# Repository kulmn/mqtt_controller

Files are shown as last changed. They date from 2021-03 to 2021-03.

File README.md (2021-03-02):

# External device controller with timers and MQTT protocol.

Hardware: 
- Schematic diagram (Autodesk EAGLE) in /schematic/ dir
- MCU: STM32L152CB, STM32F030F4 ([firmware](https://github.com/kulmn/lcd_hd44780_f030x4))
- Ethernet: WIZnet W5500
- Indicator: HD44780 16x2

Firmware:
- GCC Eclipse project, FreeRTOS, LibOpenCM3

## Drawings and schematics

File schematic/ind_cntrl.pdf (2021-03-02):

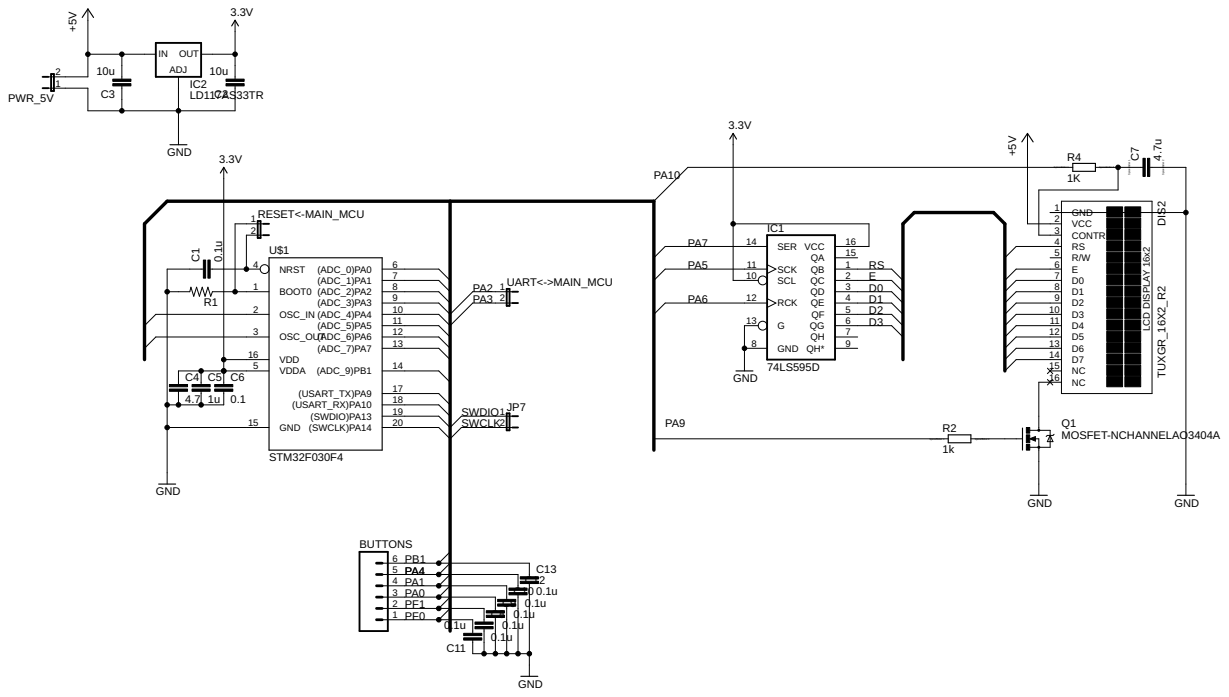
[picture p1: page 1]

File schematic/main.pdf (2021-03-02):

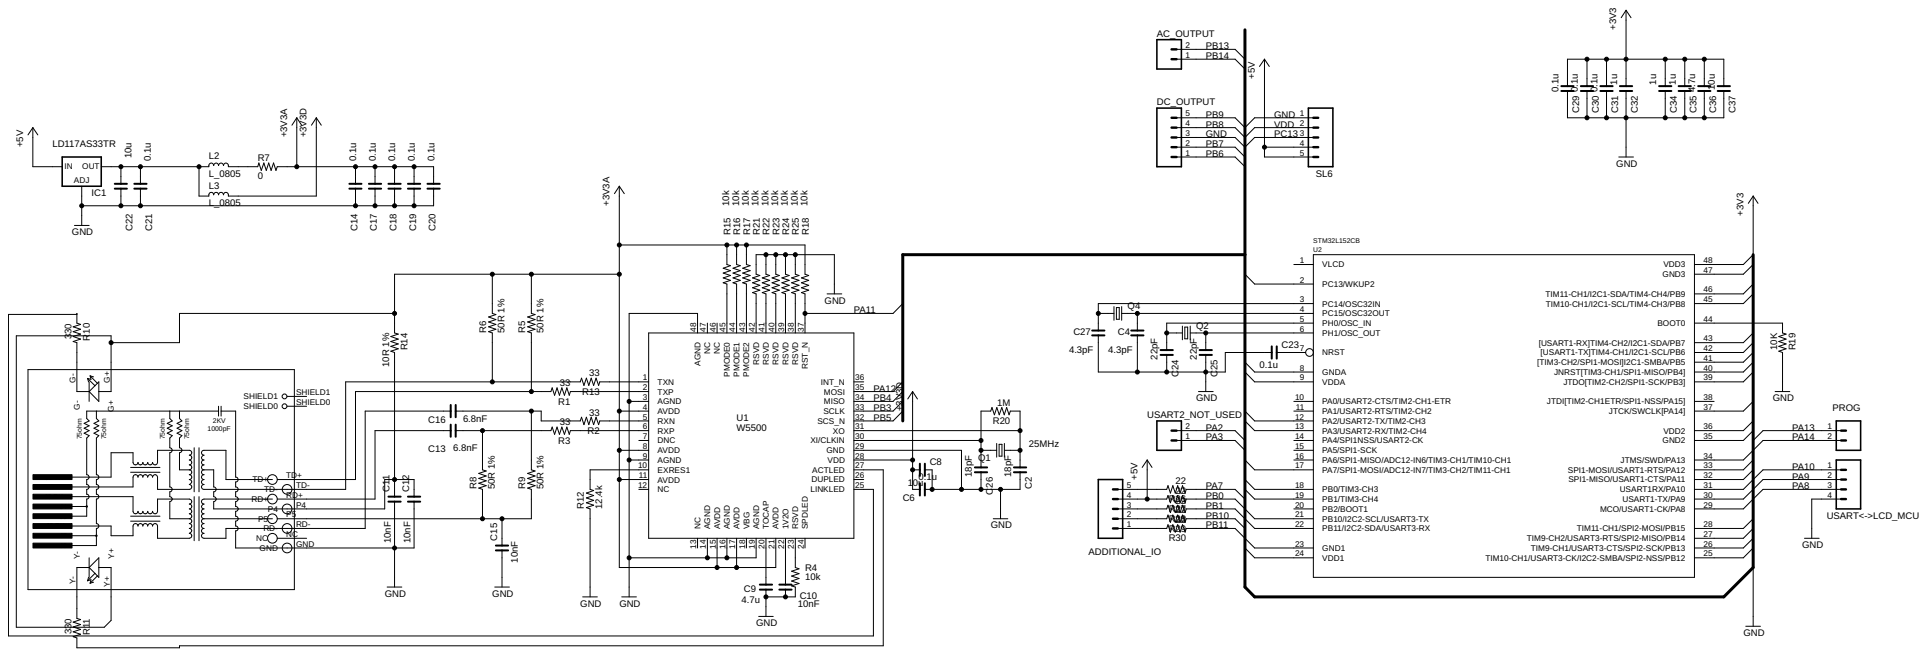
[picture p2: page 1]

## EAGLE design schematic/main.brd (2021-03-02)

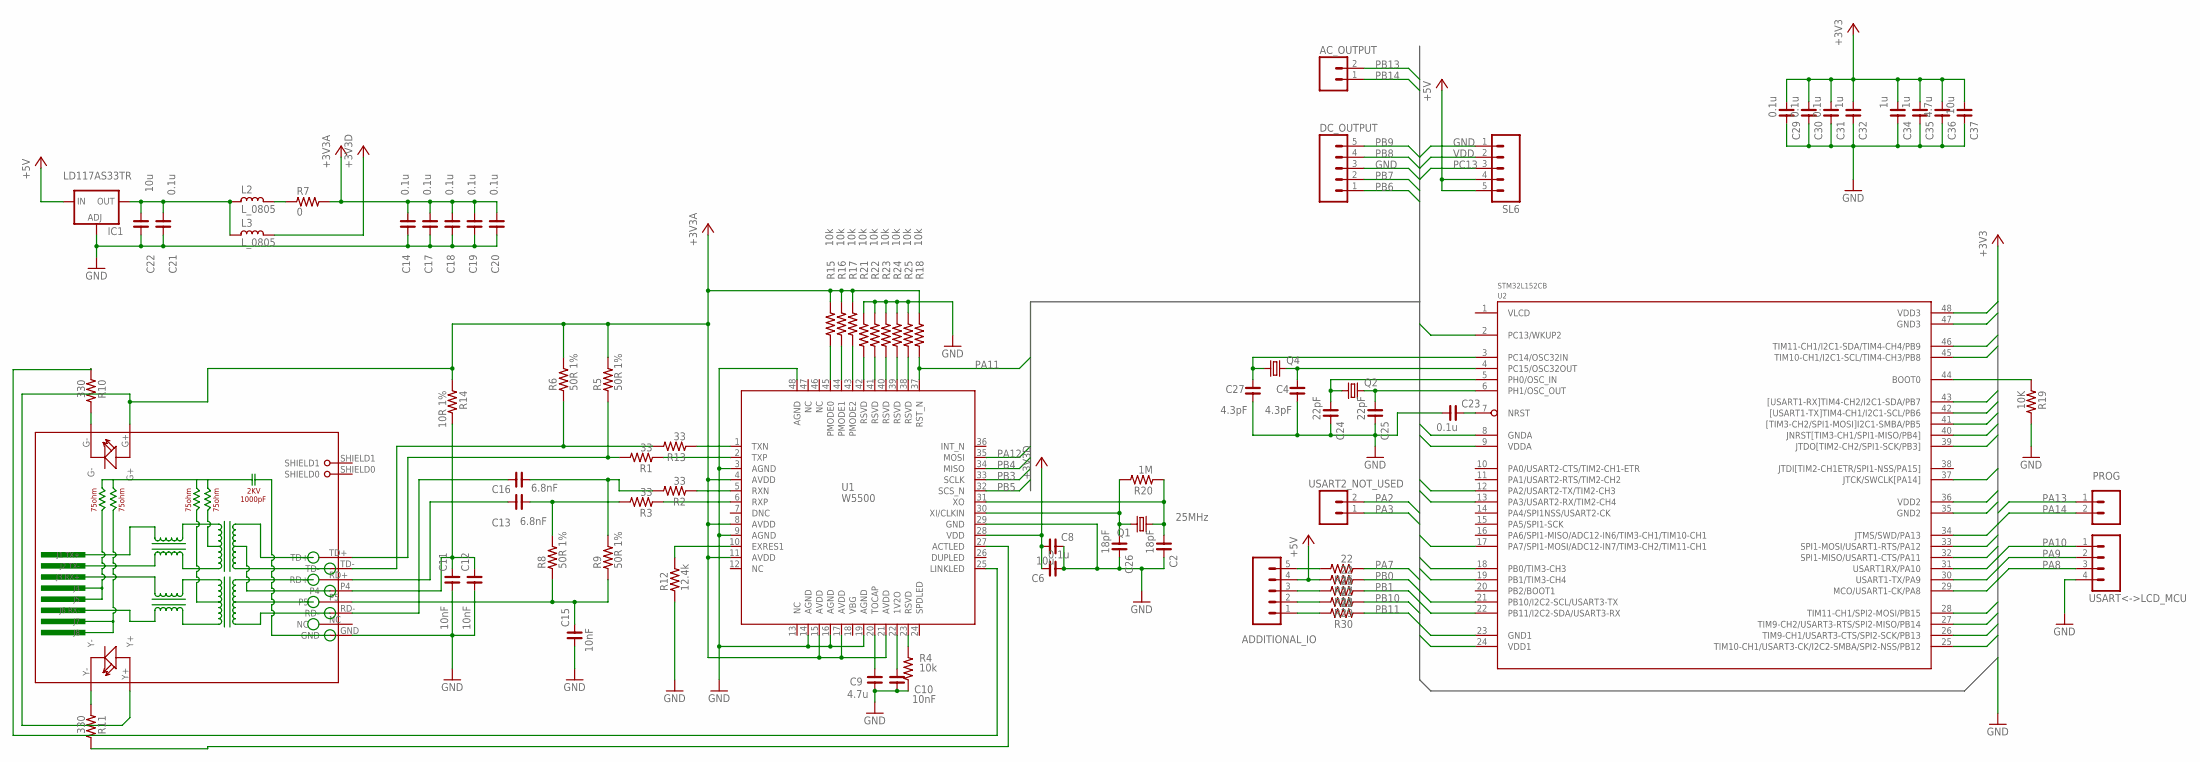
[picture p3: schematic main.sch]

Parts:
AC_OUTPUT: M02; 02P
ADDITIONAL_IO: M05; 05P
C2, C26: 18pF; C0603
C4, C27: 4.3pF; C0603
C6, C14, C17, C18, C19, C20, C21, C23, C29, C30, C31: 0.1u; C0805
C8, C22, C37: 10u; C0805
C9, C36: 4.7u; C0805
C10, C11, C12, C15: 10nF; C0603
C13, C16: 6.8nF; C0603
C24, C25: 22pF; C0805
C32, C34, C35: 1u; C0805
DC_OUTPUT: M05; 05P
IC1: LD117AS33TR; SOT223
L2, L3: L_0805; L0805
PROG: M02; 02P
Q1: 25MHz; HC49U-V
Q2: CRYSTALHC49U-V; HC49U-V
Q4: CRYSTALTC26H; TC26H
R1, R2, R3, R13: 33; R0603
R4, R15, R16, R17, R18, R21, R22, R23, R24, R25: 10k; R0603
R5, R6, R8, R9: 50R 1%; R0603
R7: 0; R1206
R10, R11: 330; R0805
R12: 12.4k; R0805
R14: 10R 1%; R0603
R19: 10K; R1206
R20: 1M; R0805
R26, R27, R28, R29, R30: 22; R0805
RJ1: HR911105A
SL6: M05; 05P
U1: W5500
U2: STM32L152CB; LQFP48-7X7
USART2_NOT_USED: M02; 02P
USART<->LCD_MCU: M04; 04P

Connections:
+3V3A: C14.1, C17.1, C18.1, C19.1, C20.1, R5.2, R6.2, R7.2, R14.1, R15.2, R16.2, R17.2, R18.2, RJ1.G+, RJ1.Y+, U1.4 (AVDD), U1.8 (AVDD), U1.11 (AVDD), U1.15 (AVDD), U1.17 (AVDD), U1.21 (AVDD)
+3V3D: C6.2, C8.1, L3.1, U1.28 (VDD)
+5V: ADDITIONAL_IO.4, IC1.3 (IN), R27.2, SL6.4, SL6.5
GND: C2.2, C4.1, C6.1, C8.2, C9.2, C10.1, C11.1, C12.1, C14.2, C15.1, C17.2, C18.2, C19.2, C20.2, C21.2, C22.2, C23.1, C24.2, C25.2, C26.2, C27.1, C29.2, C30.2, C31.2, C32.2, C34.2, C35.2, C36.2, C37.2, DC_OUTPUT.3, IC1.1 (ADJ), R4.2, R12.1, R19.2, R21.2, R22.2, R23.2, R24.2, R25.2, RJ1.GND, SL6.1, U1.3 (AGND), U1.9 (AGND), U1.14 (AGND), U1.16 (AGND), U1.19 (AGND), U1.29 (GND), U1.48 (AGND), U2.8 (GNDA), U2.23 (GND1), U2.35 (GND2), U2.47 (GND3), USART<->LCD_MCU.4
unnamed: C9.1, U1.20 (TOCAP)
unnamed: C10.2, U1.22 (1V2O)
unnamed: R13.1, U1.1 (TXN)
unnamed: C2.1, Q1.1, R20.1, U1.31 (XO)
unnamed: C26.1, Q1.2, R20.2, U1.30 (XI/CLKIN)
unnamed: R1.1, U1.2 (TXP)
unnamed: R2.1, U1.5 (RXN)
unnamed: R3.1, U1.6 (RXP)
unnamed: R4.1, U1.23 (RSVD)
unnamed: C21.1, C22.1, IC1.4 (OUT), L2.2, L3.2
unnamed: C16.1, R2.2, R9.2
unnamed: C13.1, R3.2, R8.2
unnamed: L2.1, R7.1
unnamed: R10.2, RJ1.G-
unnamed: C11.2, C12.2, R14.2, RJ1.P4
unnamed: R11.1, RJ1.Y-
unnamed: R6.1, R13.2, RJ1.TD-
unnamed: C13.2, RJ1.RD+
unnamed: R10.1, U1.25 (LINKLED)
unnamed: R11.2, U1.27 (ACTLED)
unnamed: R16.1, U1.44 (PMODE1)
unnamed: R15.1, U1.45 (PMODE0)
unnamed: R17.1, U1.43 (PMODE2)
unnamed: C16.2, RJ1.RD-
unnamed: R12.2, U1.10 (EXRES1)
unnamed: R1.2, R5.1, RJ1.TD+
unnamed: C15.2, R8.1, R9.1, RJ1.P5
unnamed: ADDITIONAL_IO.5, R26.2
unnamed: C23.2, U2.7 (NRST)
unnamed: R19.1, U2.44 (BOOT0)
unnamed: C27.2, Q4.1, U2.3 (PC14/OSC32IN)
unnamed: C24.1, Q2.1, U2.5 (PH0/OSC_IN)
unnamed: C25.1, Q2.2, U2.6 (PH1/OSC_OUT)
unnamed: C4.2, Q4.2, U2.4 (PC15/OSC32OUT)
unnamed: ADDITIONAL_IO.3, R28.2
unnamed: ADDITIONAL_IO.2, R29.2
unnamed: R21.1, U1.42 (RSVD)
unnamed: R22.1, U1.41 (RSVD)
unnamed: R23.1, U1.40 (RSVD)
unnamed: R24.1, U1.39 (RSVD)
unnamed: R25.1, U1.38 (RSVD)
unnamed: ADDITIONAL_IO.1, R30.2
PA2: U2.12 (PA2/USART2-TX/TIM2-CH3), USART2_NOT_USED.2
PA3: U2.13 (PA3/USART2-RX/TIM2-CH4), USART2_NOT_USED.1
PA7: R26.1, U2.17 (PA7/SPI1-MOSI/ADC12-IN7/TIM3-CH2/TIM11-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)
PA8: U2.29 (MCO/USART1-CK/PA8), USART<->LCD_MCU.3
PA9: U2.30 (USART1-TX/PA9), USART<->LCD_MCU.2
PA10: U2.31 (USART1RX/PA10), USART<->LCD_MCU.1
PA11: R18.1, U1.37 (RST_N), U2.32 (SPI1-MISO/USART1-CTS/PA11)
PA12: U1.35 (MOSI), U2.33 (SPI1-MOSI/USART1-RTS/PA12)
PA13: PROG.1, U2.34 (JTMS/SWD/PA13)
PA14: PROG.2, U2.37 (JTCK/SWCLK[PA14])
PB0: R27.1, U2.18 (PB0/TIM3-CH3)
PB1: R28.1, U2.19 (PB1/TIM3-CH4)
PB3: U1.33 (SCLK), U2.39 (JTDO[TIM2-CH2/SPI1-SCK/PB3])
PB4: U1.34 (MISO), U2.40 (JNRST[TIM3-CH1/SPI1-MISO/PB4])
PB5: U1.32 (SCS_N), U2.41 ([TIM3-CH2/SPI1-MOSI]I2C1-SMBA/PB5)
PB6: DC_OUTPUT.1, U2.42 ([USART1-TX]TIM4-CH1/I2C1-SCL/PB6)
PB7: DC_OUTPUT.2, U2.43 ([USART1-RX]TIM4-CH2/I2C1-SDA/PB7)
PB8: DC_OUTPUT.4, U2.45 (TIM10-CH1/I2C1-SCL/TIM4-CH3/PB8)
PB9: DC_OUTPUT.5, U2.46 (TIM11-CH1/I2C1-SDA/TIM4-CH4/PB9)
PB10: R29.1, U2.21 (PB10/I2C2-SCL/USART3-TX)
PB11: R30.1, U2.22 (PB11/I2C2-SDA/USART3-RX)
PB12: U2.25 (TIM10-CH1/USART3-CK/I2C2-SMBA/SPI2-NSS/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)
PB13: AC_OUTPUT.2, U2.26 (TIM9-CH1/USART3-CTS/SPI2-SCK/PB13)
PB14: AC_OUTPUT.1, U2.27 (TIM9-CH2/USART3-RTS/SPI2-MISO/PB14)
PB15: U2.28 (TIM11-CH1/SPI2-MOSI/PB15)
PC13: SL6.3, U2.2 (PC13/WKUP2)
VDD: C29.1, C30.1, C31.1, C32.1, C34.1, C35.1, C36.1, C37.1, SL6.2, U2.9 (VDDA), U2.24 (VDD1), U2.36 (VDD2), U2.48 (VDD3)

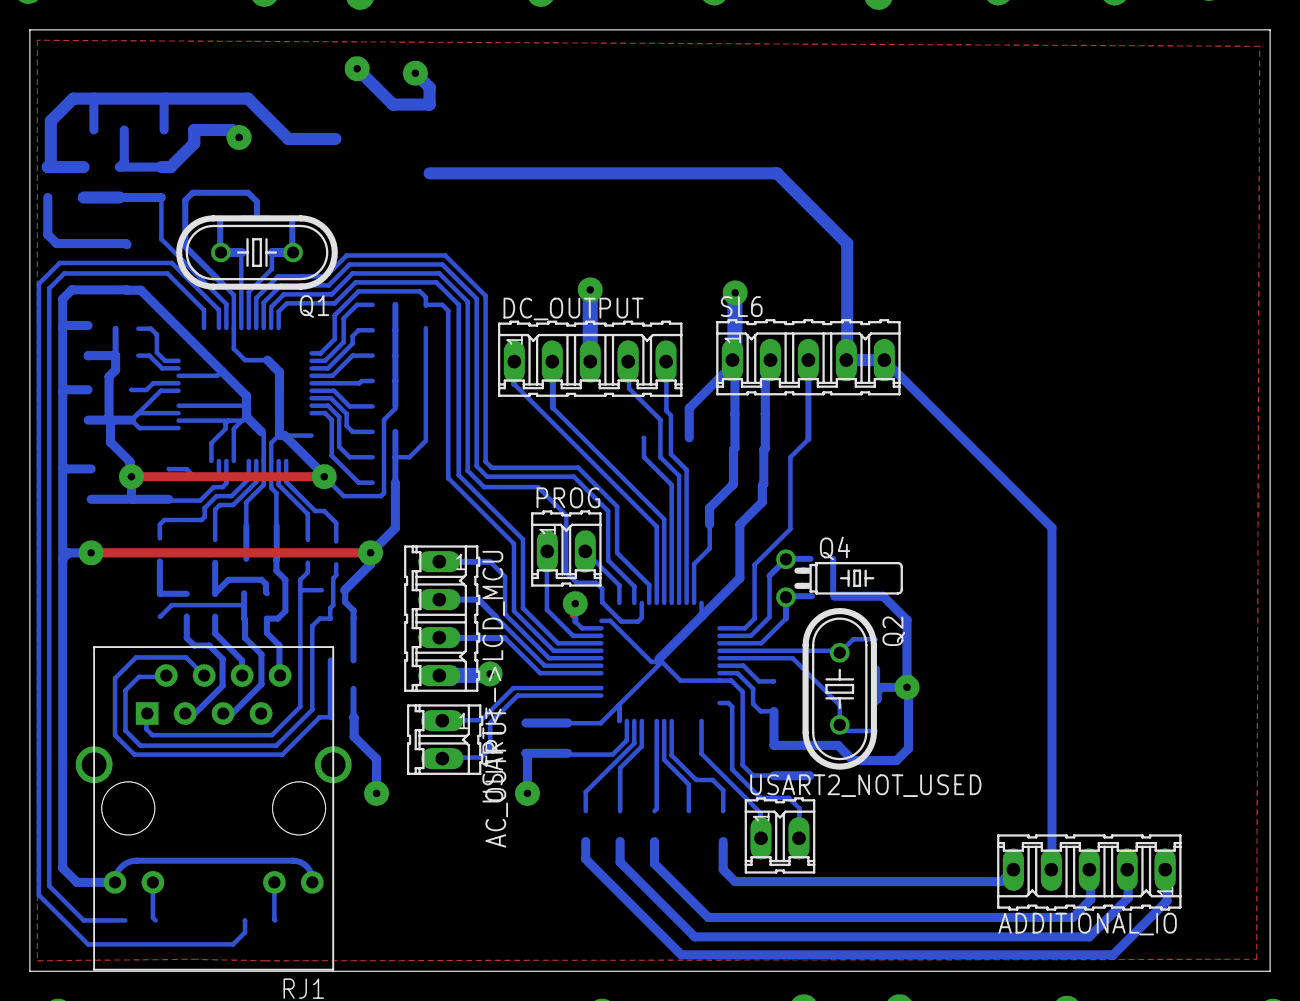
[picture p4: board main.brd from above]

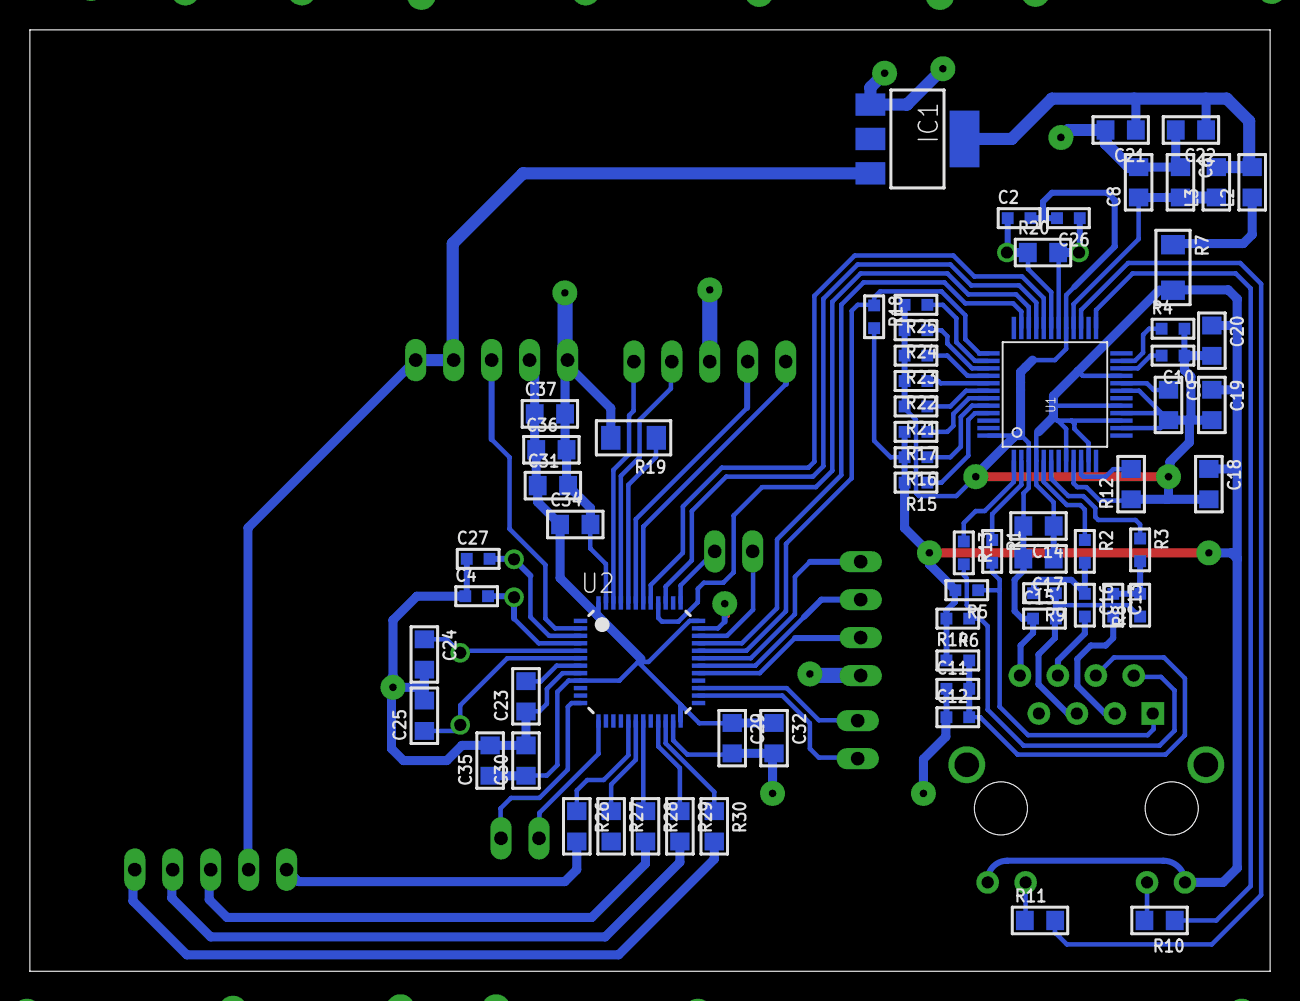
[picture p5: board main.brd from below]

Board: 2 copper layers, 83.0 x 63.0 mm, 77 parts (66 on the bottom side), 71 nets.

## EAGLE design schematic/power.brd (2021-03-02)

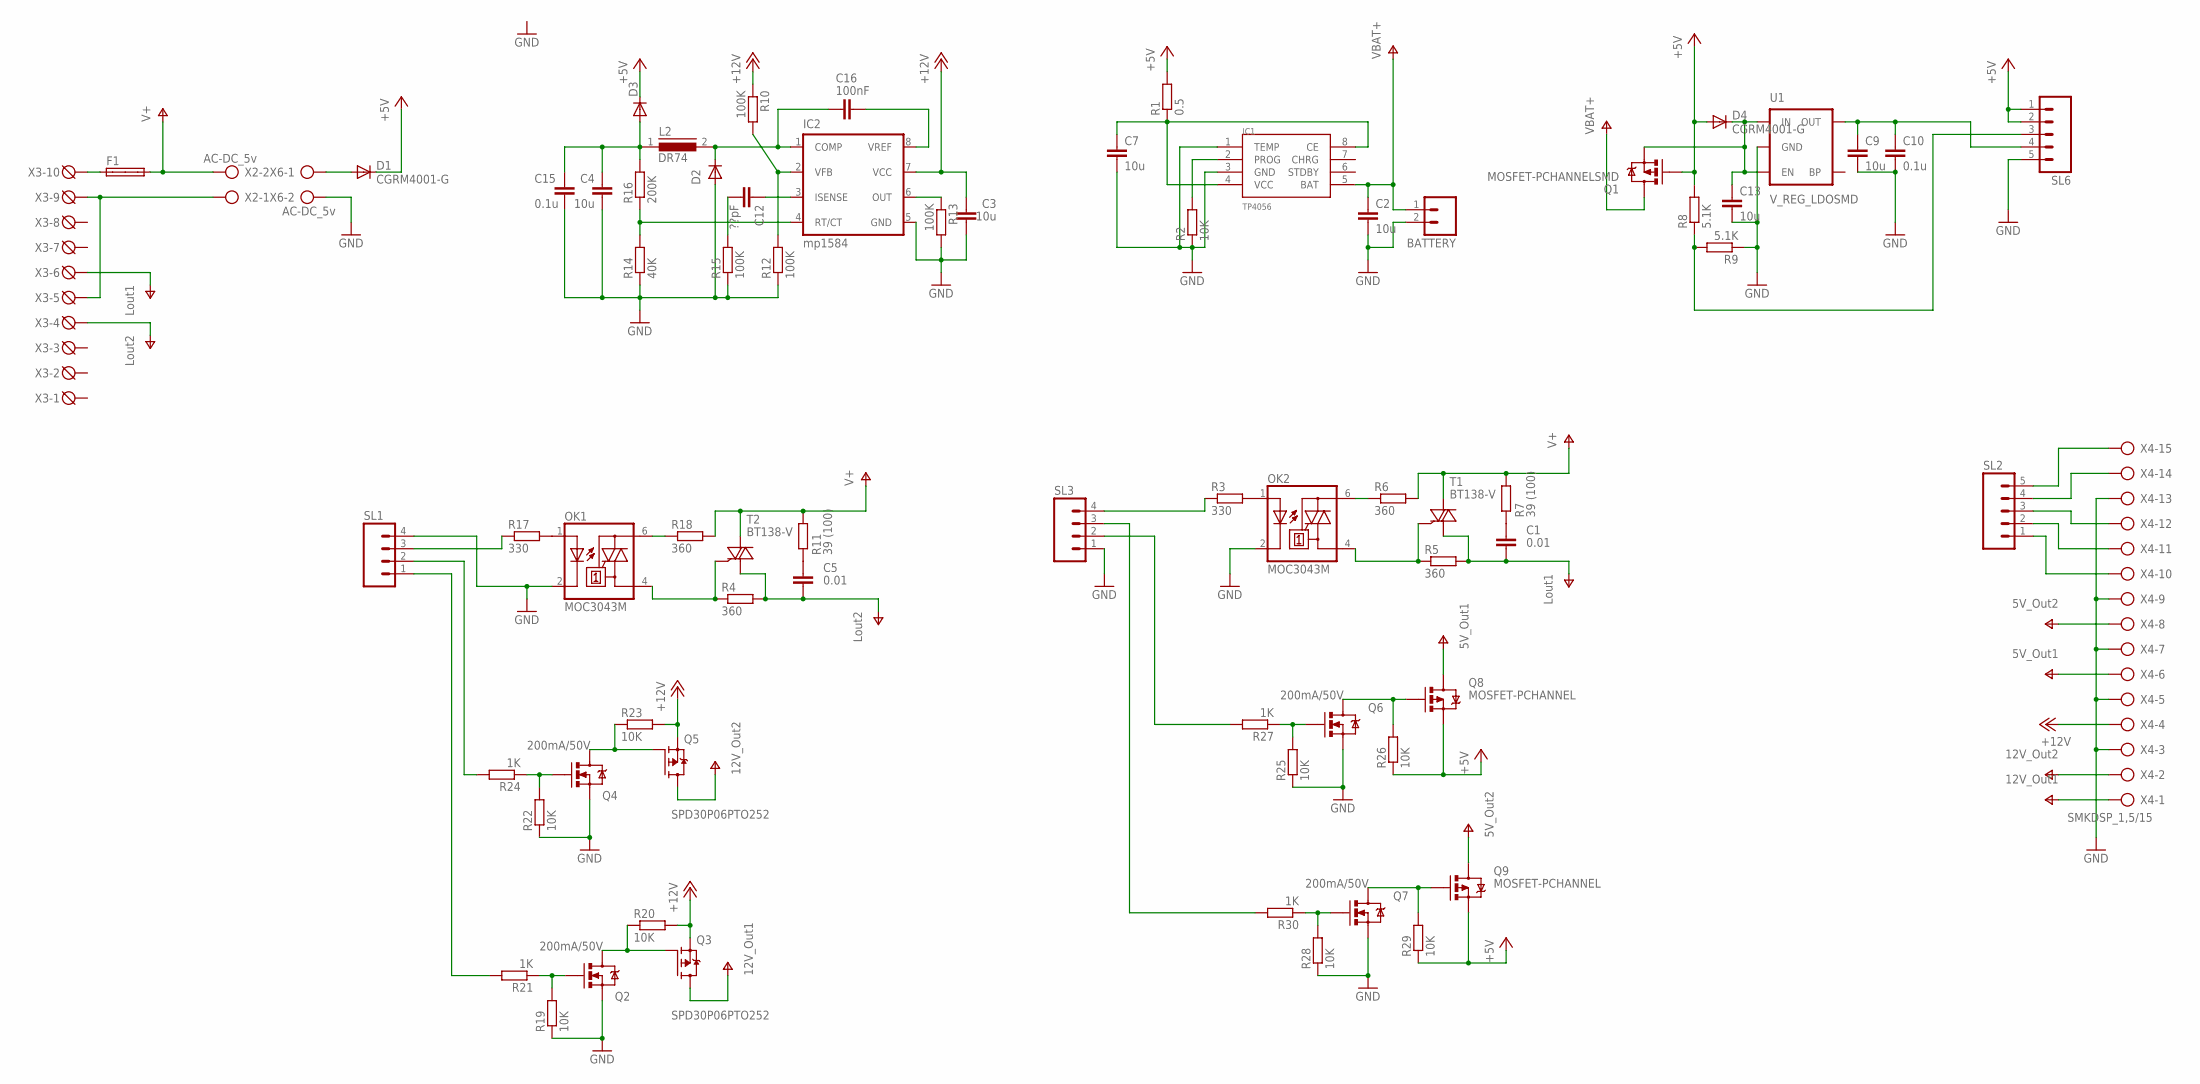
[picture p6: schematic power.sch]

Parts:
BATTERY: M02; 02P
C1, C5: 0.01; C075-032X103
C2, C7, C9, C13: 10u; C0805
C3, C4: 10u; C1206
C10, C15: 0.1u; C0805
C12: ??pF; C0603
C16: 100nF; C0603
D1, D3, D4: CGRM4001-G; SOD-123_MINI-SMA
D2: ES2D; SMB
F1: SHK20L
IC1: TP4056; SOP-8
IC2: mp1584; SO-08
L2: DR74
OK1, OK2: MOC3043M; DIL06
Q1: MOSFET-PCHANNELSMD; SOT23-3
Q2, Q4, Q6, Q7: 200mA/50V; SOT23-3
Q3, Q5: SPD30P06PTO252; TO252
Q8, Q9: MOSFET-PCHANNEL; SOT23-3
R1: 0.5; R0805
R2, R19, R20, R22, R23, R25, R26, R28, R29: 10K; R0805
R3, R17: 330; R1206
R4, R5: 360; 0204/7
R6, R18: 360; R1206
R7, R11: 39 (100); 0411/12
R8, R9: 5.1K; R0805
R10, R12, R13, R15: 100K; R0603
R14: 40K; R0603
R16: 200K; R0603
R21, R24, R27, R30: 1K; R0805
SL1, SL3: M04; 04P
SL2, SL6: M05; 05P
T1, T2: BT138-V; TO220BV
U1: V_REG_LDOSMD; SOT23-5
X2, X6: AC-DC_5v; AK300/2
X3: DG3XX-10; DG129-7.5-10P
X4: SMKDSP_1,5/15

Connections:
5V_OUT1: Q8.3 (D), X4.6
5V_OUT2: Q9.3 (D), X4.8
12V_OUT1: Q3.3 (D), X4.1
12V_OUT2: Q5.3 (D), X4.2
+5V: D1.C, D3.C, D4.A, Q1.1 (G), Q8.2 (S), Q9.2 (S), R1.2, R8.2, R26.1, R29.1, SL6.1, SL6.2
+12V: C3.2, IC2.7 (VCC), Q3.2 (S), Q5.2 (S), R10.1, R20.2, R23.2, X4.4
GND: BATTERY.2, C2.2, C3.1, C4.1, C7.2, C9.2, C10.2, C13.2, C15.2, D2.A, IC1.1 (TEMP), IC1.3 (GND), IC2.5 (GND), OK1.2 (C), OK2.2 (C), Q2.2 (S), Q4.2 (S), Q6.2 (S), Q7.2 (S), R2.1, R9.1, R12.1, R13.2, R14.1, R15.1, R19.1, R22.1, R25.1, R28.1, SL1.4, SL3.1, SL6.5, U1.2 (GND), X4.3, X4.5, X4.7, X4.9, X4.13, X6.2
LOUT1: C1.2, R5.2, T1.T1 (A1), X3.6
LOUT2: C5.2, R4.2, T2.T1 (A1), X3.4
unnamed: OK2.4 (A1), R5.1, T1.G
unnamed: IC1.2 (PROG), R2.2
unnamed: C7.1, IC1.4 (VCC), IC1.8 (CE), R1.1
unnamed: OK2.6 (A2), R6.1
unnamed: C9.1, C10.1, SL6.4, U1.5 (OUT)
unnamed: X2.1, X3.5, X3.9
unnamed: F1.1A, X3.10
unnamed: R30.2, SL3.3
unnamed: OK1.4 (A1), R4.1, T2.G
unnamed: C1.1, R7.1
unnamed: D1.A, X6.1
unnamed: C13.1, D4.C, Q1.2 (S), U1.1 (IN), U1.3 (EN)
unnamed: R8.1, R9.2, SL6.3
unnamed: OK2.1 (A), R3.2
unnamed: R27.2, SL3.2
unnamed: IC2.2 (VFB), R10.2, R12.2
unnamed: IC2.6 (OUT), R13.1
unnamed: IC2.4 (RT/CT), R14.2, R16.1
unnamed: C12.2, R15.2
unnamed: C12.1, IC2.3 (ISENSE)
unnamed: C16.1, IC2.8 (VREF)
unnamed: C5.1, R11.1
unnamed: Q2.3 (D), Q3.1 (G), R20.1
unnamed: C4.2, C15.1, D3.A, L2.1, R16.2
unnamed: C16.2, D2.C, IC2.1 (COMP), L2.2
unnamed: R17.1, SL1.3
unnamed: Q6.3 (D), Q8.1 (G), R26.2
unnamed: OK1.1 (A), R17.2
unnamed: SL2.1, X4.10
unnamed: OK1.6 (A2), R18.1
unnamed: Q2.1 (G), R19.2, R21.1
unnamed: Q4.3 (D), Q5.1 (G), R23.1
unnamed: Q4.1 (G), R22.2, R24.1
unnamed: Q6.1 (G), R25.2, R27.1
unnamed: Q7.1 (G), R28.2, R30.1
unnamed: Q7.3 (D), Q9.1 (G), R29.2
unnamed: R24.2, SL1.2
unnamed: R21.2, SL1.1
unnamed: R3.1, SL3.4
unnamed: SL2.2, X4.11
unnamed: SL2.3, X4.12
unnamed: SL2.4, X4.14
unnamed: SL2.5, X4.15
V+: F1.2A, R6.2, R7.2, R11.2, R18.2, T1.T2 (A2), T2.T2 (A2), X2.2
VBAT: BATTERY.1, C2.1, IC1.5 (BAT), Q1.3 (D)

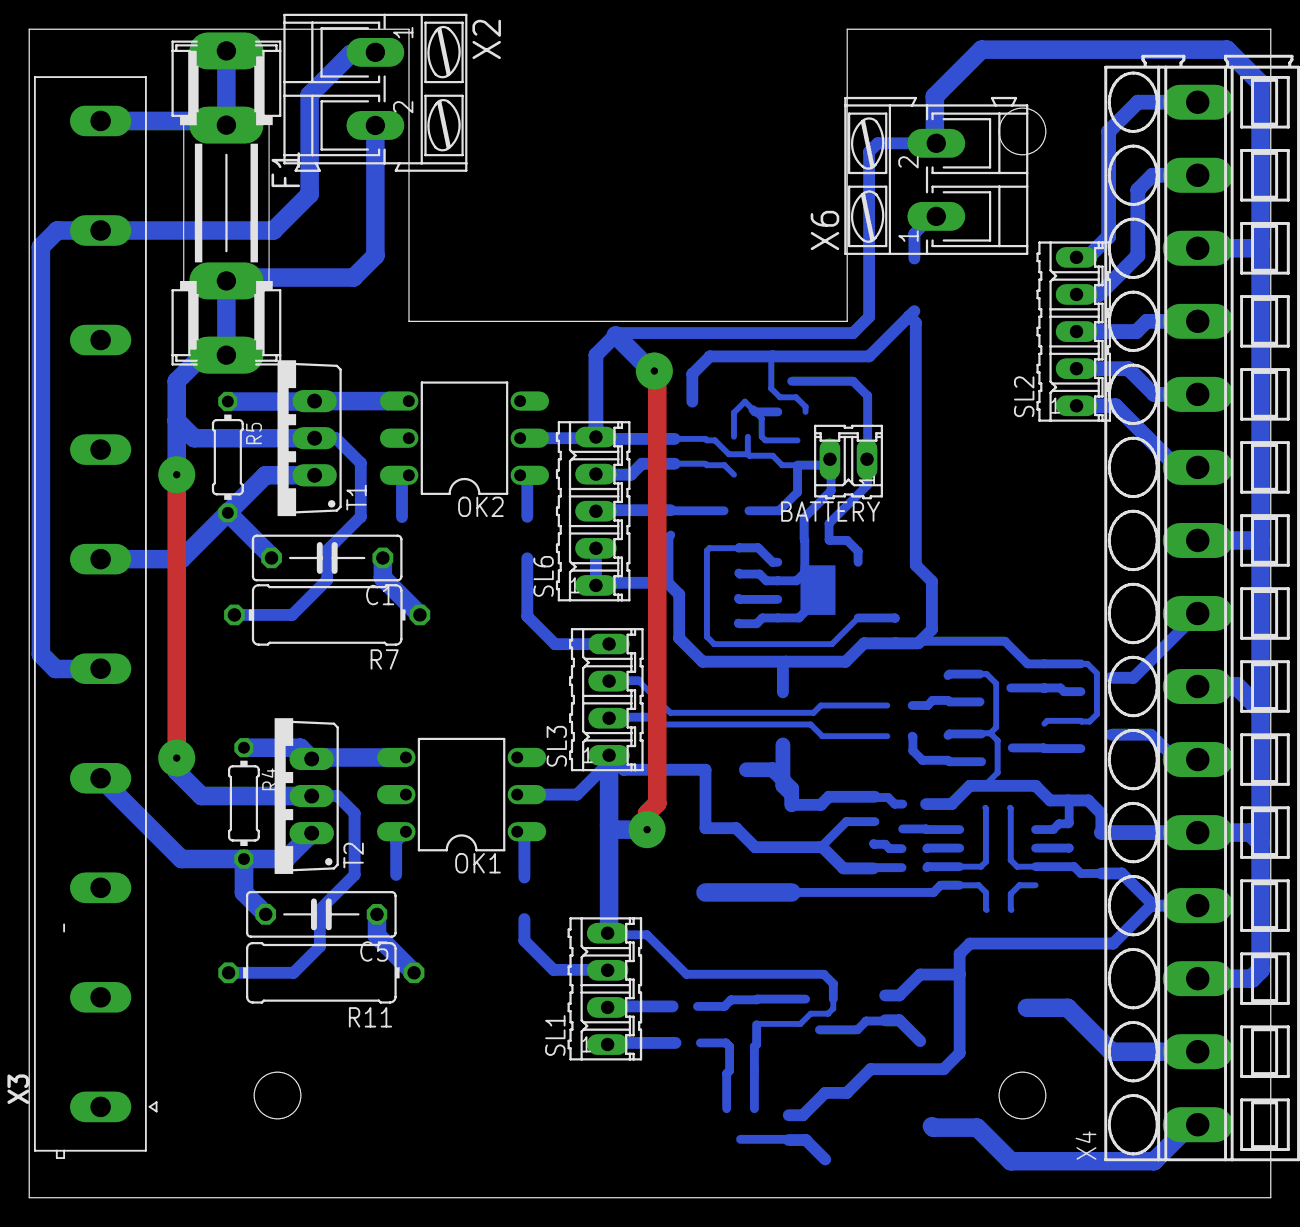
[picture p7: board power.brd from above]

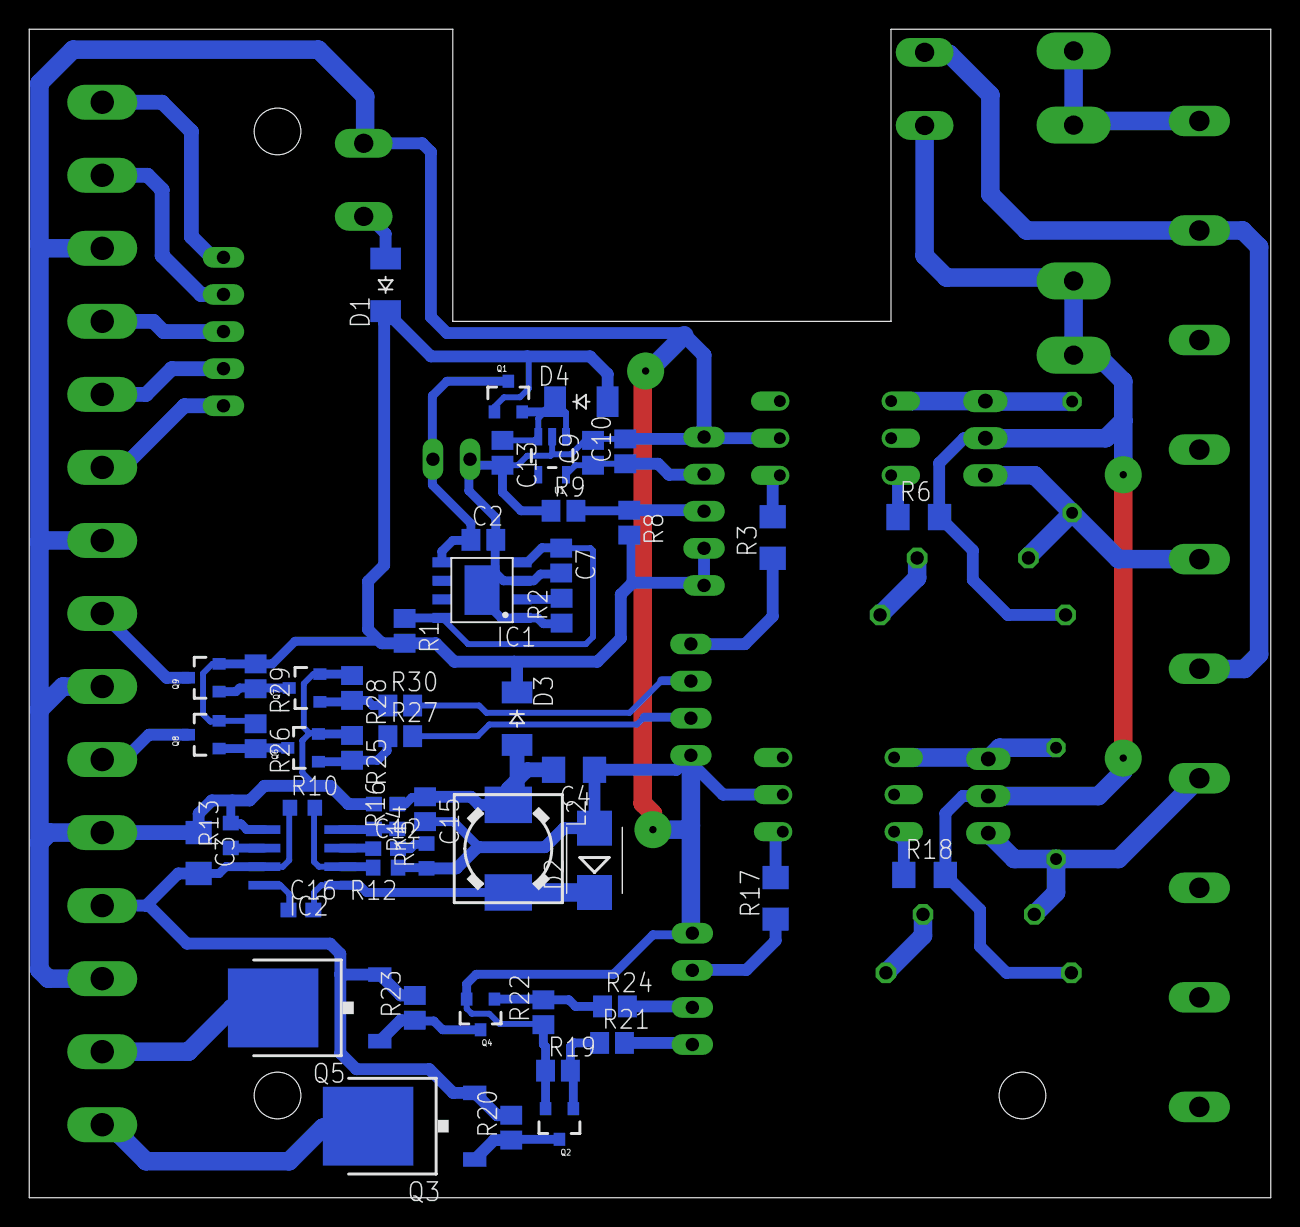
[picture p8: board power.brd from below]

Board: 2 copper layers, 85.0 x 80.0 mm, 73 parts (53 on the bottom side), 54 nets.

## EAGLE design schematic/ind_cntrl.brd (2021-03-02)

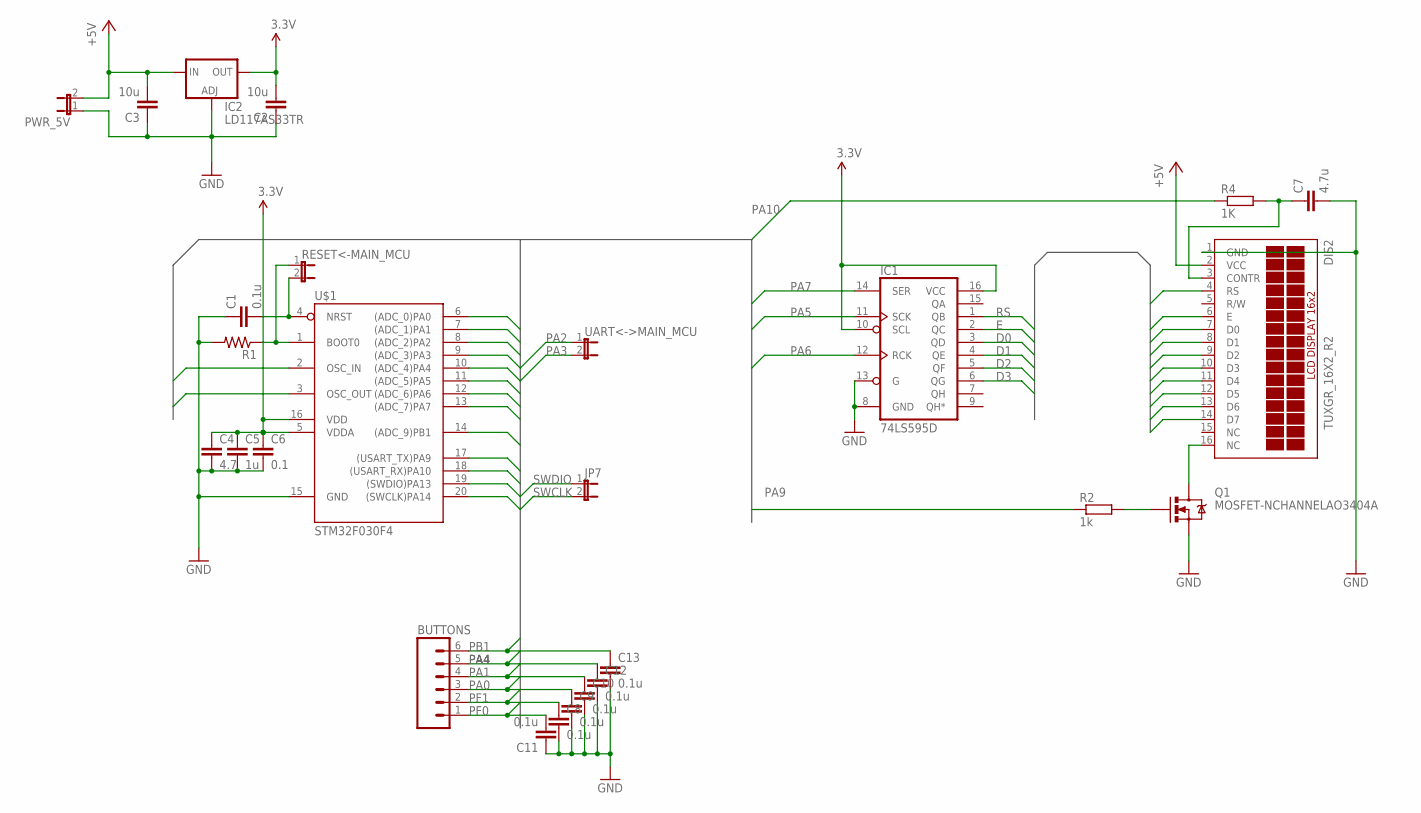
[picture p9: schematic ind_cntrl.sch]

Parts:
BUTTONS: M06; 06P
C1, C8, C9, C10, C11, C12, C13: 0.1u; 0805
C2, C3: 10u; 0805
C4: 4.7; 0805
C5: 1u; 0805
C6: 0.1; 0805
C7: 4.7u; C1206
DIS2: TUXGR_16X2_R2
IC1: 74LS595D; SO16
IC2: LD117AS33TR; SOT223
JP7: JP1E; JP1
PWR_5V: JP1E; JP1
Q1: MOSFET-NCHANNELAO3404A; SOT23-3
R1: RESISTOR0805-RES; 0805
R2: 1k; R0805
R4: 1K; R0805
RESET<-MAIN_MCU: JP1E; JP1
U$1: STM32F030F4; 2QSP20
UART<->MAIN_MCU: JP1E; JP1

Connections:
3.3V: C2.2, C4.1, C5.1, C6.1, IC1.10 (SCL), IC1.16 (VCC), IC2.4 (OUT), U$1.5 (VDDA), U$1.16 (VDD)
+5V: C3.2, DIS2.2 (VCC), IC2.3 (IN), PWR_5V.2
D0: DIS2.7 (D0), IC1.3 (QD)
D1: DIS2.8 (D1), IC1.4 (QE)
D2: DIS2.9 (D2), IC1.5 (QF)
D3: DIS2.10 (D3), IC1.6 (QG)
D4: DIS2.11 (D4)
D5: DIS2.12 (D5)
D6: DIS2.13 (D6)
D7: DIS2.14 (D7)
E: DIS2.6 (E), IC1.2 (QC)
GND: C1.1, C2.1, C3.1, C4.2, C5.2, C6.2, C7.2, C8.2, C9.2, C10.2, C11.1, C12.2, C13.2, DIS2.1 (GND), IC1.8 (GND), IC1.13 (G), IC2.1 (ADJ), PWR_5V.1, Q1.2 (S), R1.2, U$1.15 (GND)
unnamed: C1.2, RESET<-MAIN_MCU.2, U$1.4 (NRST)
unnamed: R1.1, RESET<-MAIN_MCU.1, U$1.1 (BOOT0)
unnamed: C7.1, DIS2.3 (CONTR), R4.2
unnamed: Q1.1 (G), R2.2
unnamed: DIS2.16 (NC), Q1.3 (D)
PA0: BUTTONS.3, C9.1, U$1.6 ((ADC_0)PA0)
PA1: BUTTONS.4, C10.1, U$1.7 ((ADC_1)PA1)
PA2: U$1.8 ((ADC_2)PA2), UART<->MAIN_MCU.1
PA3: U$1.9 ((ADC_3)PA3), UART<->MAIN_MCU.2
PA4: BUTTONS.5, C12.1, U$1.10 ((ADC_4)PA4)
PA5: IC1.11 (SCK), U$1.11 ((ADC_5)PA5)
PA6: IC1.12 (RCK), U$1.12 ((ADC_6)PA6)
PA7: IC1.14 (SER), U$1.13 ((ADC_7)PA7)
PA9: R2.1, U$1.17 ((USART_TX)PA9)
PA10: R4.1, U$1.18 ((USART_RX)PA10)
PB1: BUTTONS.6, C13.1, U$1.14 ((ADC_9)PB1)
PF0: BUTTONS.1, C11.2, U$1.2 (OSC_IN)
PF1: BUTTONS.2, C8.1, U$1.3 (OSC_OUT)
RS: DIS2.4 (RS), IC1.1 (QB)
SWCLK: JP7.2, U$1.20 ((SWCLK)PA14)
SWDIO: JP7.1, U$1.19 ((SWDIO)PA13)

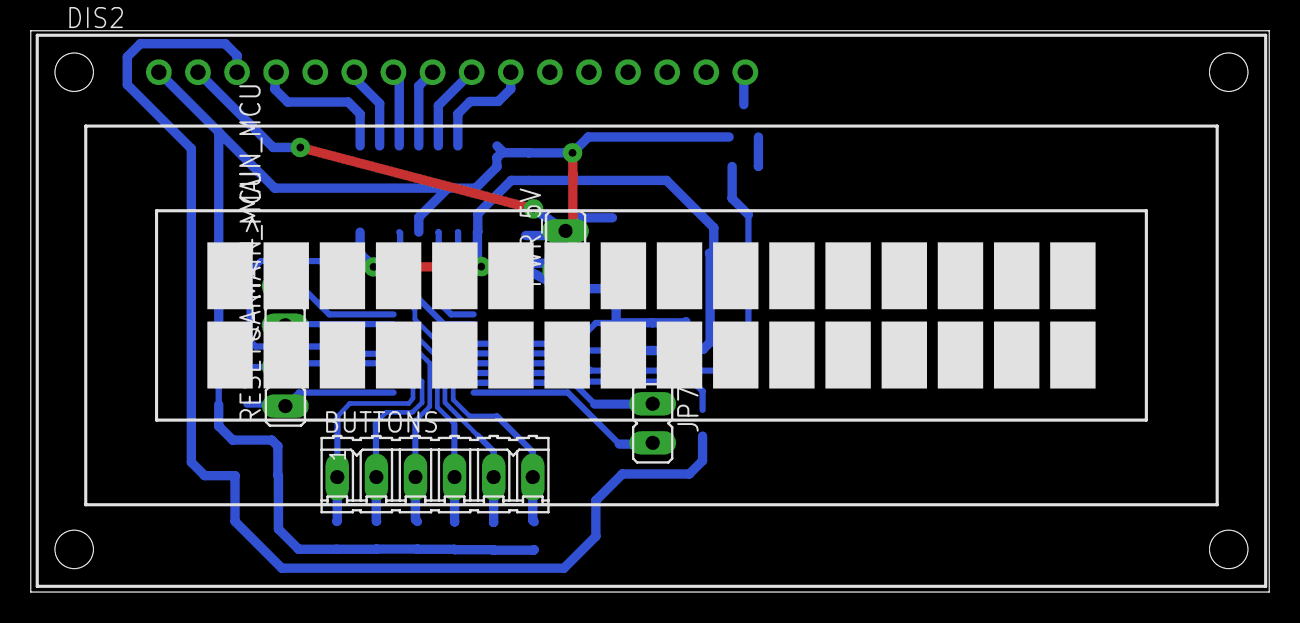
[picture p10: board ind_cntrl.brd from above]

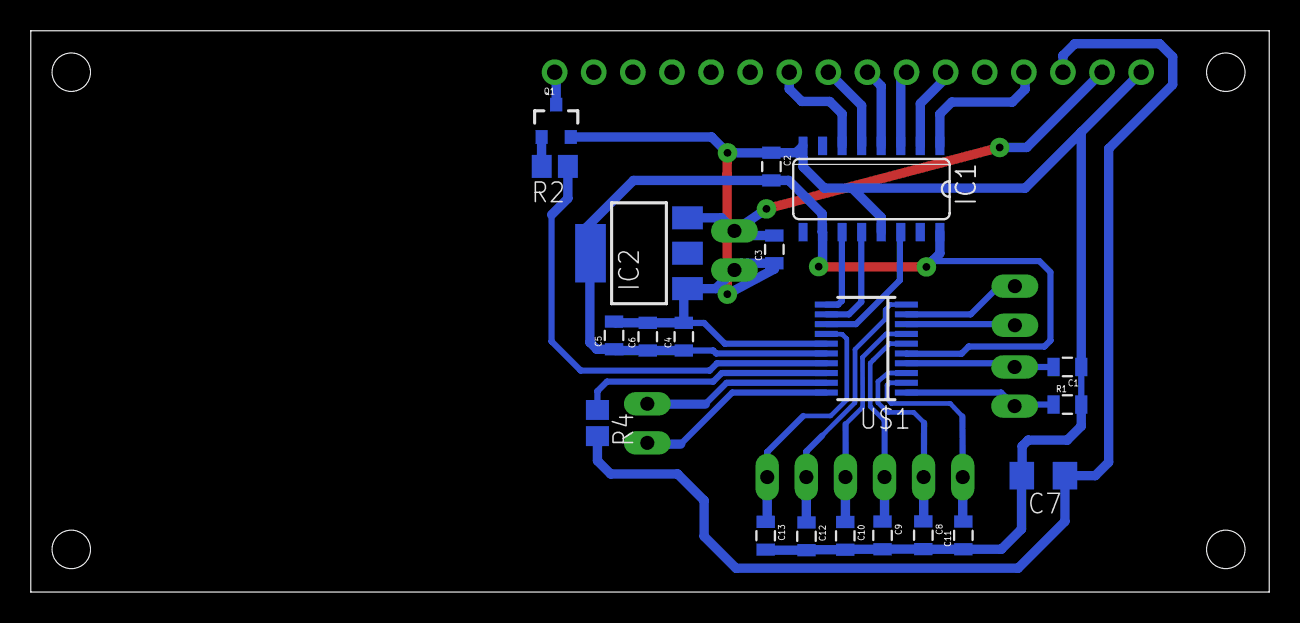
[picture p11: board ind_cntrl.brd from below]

Board: 2 copper layers, 80.5 x 36.5 mm, 26 parts (20 on the bottom side), 29 nets.

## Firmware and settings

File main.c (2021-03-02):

/*
 * main.c
 *
 *  Created on: 08 сент. 2014 г.
 *      Author: yura
 */

#include "main.h"




/******************************************************************************/
All_Chan_Config 		config;
uint8_t 				time_set_flag = 0;
uint8_t 				chan_timer_init;

SemaphoreHandle_t 		xButtons_Smphr[6];
xQueueHandle 			xLoadQueue;


/*************************Network Configuration variables********************************/
const wiz_NetInfo gWIZNETINFO = { .mac = {0x00, 0x08, 0xdc,0x00, 0xab, 0xcd},
                            	    	    	    	    .ip = {192, 168, 88, 200},  .sn = {255,255,255,0},
                            	    	    	    	    .gw = {192, 168, 88, 1},   .dns = {0,0,0,0},
                            	    	    	    	    .dhcp = NETINFO_DHCP };    // NETINFO_STATIC  NETINFO_DHCP
const wiz_NetTimeout gWIZNETTIME = {.retry_cnt = 3, .time_100us = 2000};     //RCR = 3 RTR = 2000

uint8_t 		gDATABUF[DATA_BUF_SIZE];

const uint8_t 	ntp_serv[] = {192,168,88,1};
uint8_t 	mqtt_serv[] = {192,168,88,10};

Network 		mqtt_interface;
MQTTClient 	mqtt_client;
uint8_t		mqtt_tx_buf[100];
uint8_t 		ethernet_init_flag, network_init_flag;
uint16_t 		sntp_timer, dhcp_timer, mqtt_ch_timer, mqtt_tm_timer;

/************************* Temperature sensor variables (ds18b20) ***********************/
OWI t_sensor;
OWI_STM32F0xx_GPIO_Driver t_sensor_pindriver;
DS18B20_TypeDef cur_temper;
//xQueueHandle xTemperQueue;

/************************* USART interface to LCD variables ***********************/
volatile static uint8_t usart1_rx_buf[USART1_RX_BUF_SIZE];
volatile static uint8_t usart1_tx_buf[USART1_TX_BUF_SIZE];
USART_HAL usart_1;

SLIP slip_1_pr;
SLIP_USART_Driver slip_1_pr_driver;

//volatile static uint8_t usart2_rx_buf[USART2_RX_BUF_SIZE];
//volatile static uint8_t usart2_tx_buf[USART2_TX_BUF_SIZE];
//USART_HAL usart_2;



/************************* External interrupt 10-15 handler ****************************************
void EXTI15_10_IRQHandler(void)
{
	if (exti_get_flag_status(PIN(PWR_ON_PIN ) ))
	{
		exti_reset_request(PIN(PWR_ON_PIN ) );
	}
}

/************************* Init config structure ****************************************/
void all_config_init(void)
{
	uint8_t i;

	const gpio_pin	out_chan_pins[NUM_OUTPUTS] = {{ CH_AC_1 }, { CH_AC_2 }, { CH_DC_5V_1 }, { CH_DC_5V_2 }, { CH_DC_12V_1 }, { CH_DC_12V_2 }};

	config.chan[0].pwm.timer = TIM9;
	config.chan[1].pwm.timer = TIM9;
	config.chan[2].pwm.timer = TIM4;
	config.chan[3].pwm.timer = TIM4;
	config.chan[4].pwm.timer = TIM4;
	config.chan[5].pwm.timer = TIM4;

	config.chan[0].pwm.alt_func = GPIO_AF3;
	config.chan[0].pwm.oc_id = TIM_OC1;
	config.chan[1].pwm.alt_func = GPIO_AF3;
	config.chan[1].pwm.oc_id = TIM_OC2;
	config.chan[2].pwm.alt_func = GPIO_AF2;
	config.chan[2].pwm.oc_id = TIM_OC3;
	config.chan[3].pwm.alt_func = GPIO_AF2;
	config.chan[3].pwm.oc_id = TIM_OC4;
	config.chan[4].pwm.alt_func = GPIO_AF2;
	config.chan[4].pwm.oc_id = TIM_OC2;
	config.chan[5].pwm.alt_func = GPIO_AF2;
	config.chan[6].pwm.oc_id = TIM_OC1;

	config.lcd_brightness = 80;
	config.lcd_contrast = 20;

	config.load_cntrl_en = 0;

	for (i = 0; i < NUM_OUTPUTS; i++)
	{
		config.chan[i].pin = out_chan_pins[i];
		config.chan[i].enabled = 0;
		config.chan[i].pwm.enabled = 0;
		config.chan[i].pwm.perc = 50;
		config.chan[i].pwm.period = 1;
		config.chan[i].state =0;
		config.load[i].conn_pwr = 0;
		config.load[i].off_status = 0;
		config.load[i].priority = 0;
	}

	for (uint8_t i = 0; i < NUM_TIMERS; i++)
	{
		config.timer[i].channel = 0;
		config.timer[i].state = 0;
		config.timer[i].hour = 0;
		config.timer[i].minute = 0;
	}
}


/******************************************************************************/
uint8_t mqtt_protocol_init(void)
{
	int res;

	NewNetwork(&mqtt_interface, SOCK_MQTT );
	ConnectNetwork(&mqtt_interface, mqtt_serv, MQTT_SERV_PORT );
	MQTTClientInit(&mqtt_client, &mqtt_interface, 1000, mqtt_tx_buf, 100, gDATABUF, 2048 );

	MQTTPacket_connectData data = MQTTPacket_connectData_initializer;
	data.willFlag = 0;
	data.MQTTVersion = 3;
	data.clientID.cstring = (char*)"pwrcntrl";
	data.username.cstring = NULL;
	data.password.cstring = NULL;
	data.keepAliveInterval = 10;
	data.cleansession = 1;

	res = MQTTConnect(&mqtt_client, &data );
	if (res == 0) return 1;
	else return 0;
}

/******************************************************************************
 Intialize the network information to be used in WIZCHIP //
 /******************************************************************************/
void network_init(void)
{
	int rc = 0;

	network_init_flag = 0;
	sntp_timer = SNTP_RUN_FRQ - SNTP_ERR_FRQ;
	dhcp_timer = DHCP_RUN_FRQ;
	mqtt_ch_timer = 0;
	mqtt_tm_timer = 0;

	w5500_init();
	ctlnetwork(CN_SET_NETINFO, (void*) &gWIZNETINFO );
	ctlnetwork(CN_SET_TIMEOUT, (void*) &gWIZNETTIME );

	ethernet_init_flag = 1;

	/* DHCP client Initialization*/
	if (gWIZNETINFO.dhcp == NETINFO_DHCP)
	{
		DHCP_init(SOCK_DHCP, gDATABUF );
	} else
	{
		SNTP_init(SOCK_NTP, (uint8_t *) ntp_serv, gDATABUF );
		network_init_flag = 1;
	}
}


/******************************************************************************/
void slip_1_protocol_init(void)
{
	slip_1_pr_driver.usart_drv = &usart_1;
	slip_1_pr_driver.interface = SLIP_USART_INTERFACE;

	slip_1_pr.bytes_received = 0;
	slip_1_pr.max_packet_size = 32;
	slip_1_pr.driver = (SLIP_Interface*) &slip_1_pr_driver;
}


/******************************************************************************/
void vEthernet_Task(void *pvParameters)
{
	TickType_t xLastWakeTime;
	const TickType_t xFrequency = ETHER_TASK_FRQ;
	xLastWakeTime = xTaskGetTickCount();

	uint8_t ip[4];
	uint32_t utc_seconds;
	datetime time;

	for (;;)
	{

		do
		{
			 vTaskDelayUntil(&xLastWakeTime, xFrequency );
		}while (wizphy_getphylink() == PHY_LINK_OFF);


		// --------------------------dhcp protocol--------------------------------
		if (ethernet_init_flag && (gWIZNETINFO.dhcp == NETINFO_DHCP) && (dhcp_timer >= DHCP_RUN_FRQ))
		{
			switch (DHCP_run())
			{
				case DHCP_IP_ASSIGN:
				case DHCP_IP_CHANGED:
					break;
				case DHCP_IP_LEASED:
					if (!network_init_flag)
					{
						getNTPfromDHCP((uint8_t *) ip );
						SNTP_init(SOCK_NTP, (uint8_t *) ip, gDATABUF );
					}
					network_init_flag = 1;
					dhcp_timer = 0;
					break;

				case DHCP_FAILED:
					break;
			}
		} else dhcp_timer++;

		if (network_init_flag)
		{
// --------------------------mqtt protocol--------------------------------
			if (mqtt_client.isconnected)
			{
				int rc = MQTTYield(&mqtt_client, 0 );
				if (rc < 0)
				{
					MQTTDisconnect(&mqtt_client );
				}

				if (mqtt_ch_timer >= MQTT_CH_DAT_FRQ)
				{
					mqtt_send_channel_param(&mqtt_client, &config );
					mqtt_ch_timer = 0;
				} else mqtt_ch_timer++;

				if (mqtt_tm_timer >= MQTT_TM_DAT_FRQ)
				{
					mqtt_send_timers_param(&mqtt_client, &config );
					mqtt_send_load_param(&mqtt_client, &config );
					mqtt_send_date_time(&mqtt_client);
					mqtt_send_temperature(&mqtt_client);
					mqtt_tm_timer = 0;
				} else mqtt_tm_timer++;
			}else
			{
				if (mqtt_protocol_init())
				{
					MQTTSubscribe(&mqtt_client, "/pwrcntrl/set/#", QOS0, mqtt_message_callback );
				}
			}
//---------------------------- sntp protocol---------------------------------------------
			if (sntp_timer >= SNTP_RUN_FRQ)
			{
				if (SNTP_run(&utc_seconds ))
				{
					rtc_hl_add_timezone(27, &utc_seconds );
					rtc_hl_utc2datetime(&time, utc_seconds );
					rtc_hl_set_dst(&time, &utc_seconds );
					rtc_hl_utc2datetime(&time, utc_seconds );

					if (time.yy >= 2017)
					{
						rtc_hl_set_time(time.hh, time.mm, time.ss );
						rtc_hl_set_date(time.yy, time.mo, time.dd, time.wd );
						time_set_flag = 1;
						sntp_timer = 0;
					}else sntp_timer = SNTP_RUN_FRQ - SNTP_ERR_FRQ;

				}else sntp_timer = SNTP_RUN_FRQ - SNTP_ERR_FRQ;
			} else sntp_timer++;
		}
	}
//	cm3_assert_not_reached();
	vTaskDelete(NULL );
}


/******************************************************************************/
void vPWMTimerTask(void *pvParameters)
{
	TickType_t xLastWakeTime;
	const TickType_t xFrequency = 600;			// 600 ms
	xLastWakeTime = xTaskGetTickCount();

	uint16_t counters [NUM_OUTPUTS];
	uint32_t utc_seconds;
	datetime time;

	for (;;)
	{
		vTaskDelayUntil(&xLastWakeTime, xFrequency );

		for (uint8_t i=0; i<NUM_OUTPUTS; i++)
		{
			Output_Chan* chan = &config.chan[i];

			if (chan->enabled)
			{
				if ((chan->pwm.enabled) && (chan->state))
				{
					counters[i]++;
					if (counters[i] > chan->pwm.period*100)
					{
						counters[i] = 0;
						gpio_set(chan->pin.gpio, chan->pin.pin);
					}

					if (counters[i] == chan->pwm.perc * chan->pwm.period)
					{
						gpio_clear(chan->pin.gpio, chan->pin.pin);
					}

				}
			}
		}
	}
}


/******************************************************************************/
void vLcdOutTask(void *pvParameters)
{
	portBASE_TYPE xStatus;

	while (1)
	{
		lcd_menu();
		vTaskDelay(200);
	}
	vTaskDelete(NULL );
}

/******************************************************************************/
void vChanTimerTask(void *pvParameters)
{
	TickType_t xLastWakeTime;
	const TickType_t xFrequency = 15000;			// 15 sec

	xLastWakeTime = xTaskGetTickCount();

	for (;;)
	{
		vTaskDelayUntil(&xLastWakeTime, xFrequency );

		if (chan_timer_init && time_set_flag)
		{
			uint16_t cur_time = rtc_hl_get_time(RTC_HL_HOURS) * 60 + rtc_hl_get_time(RTC_HL_MINUTES) ;
			for (uint8_t i = 0; i < NUM_OUTPUTS; i++)
			{
				uint8_t n_timer = out_timers_init(&config, i, cur_time);
				if (n_timer)
				{
					if (config.timer[n_timer-1].state)
					{
						auto_ch_on(&config.chan[i] );
					}else auto_ch_off(&config.chan[i] );

				}
			}
			chan_timer_init = 0;
		}


		for (uint8_t i = 0; i < NUM_TIMERS; i++)
		{
			if (time_set_flag && (config.timer[i].channel) )
			{
				if ( (config.timer[i].hour == rtc_hl_get_time(RTC_HL_HOURS))
						&& config.timer[i].minute ==  rtc_hl_get_time(RTC_HL_MINUTES) )
				{
					Output_Chan* chan = &config.chan[config.timer[i].channel-1];
					if (config.timer[i].state)
					{
						auto_ch_on(chan );
					}
					else
					{
						auto_ch_off(chan );
					}

				}
			}
		}
	}
	vTaskDelete(NULL );
}

/******************************************************************************/
void vReceiveButtonStateTask(void *pvParameters)
{
	TickType_t xLastWakeTime;
	const TickType_t xFrequency = 30;
	uint8_t buf[32];
	uint8_t size = 0;

	xLastWakeTime = xTaskGetTickCount();

	for (;;)
	{
		vTaskDelayUntil(&xLastWakeTime, xFrequency );

		size = slip_recv_packet(&slip_1_pr, buf );
		if (size)
		{
			if (ComputeCRC16(buf, size ) == 0 && (buf[0] == DEVICE_ADDR) && buf[1] == BUTTONS_DAT)
			{
				for (uint8_t i = 0; i < buf[2]; i++)
					if (buf[i + 3]) xSemaphoreGive(xButtons_Smphr[i] );
			}
		}
	}
	vTaskDelete(NULL );
}

/******************************************************************************/
void vGetTempTask (void *pvParameters)
{
	portBASE_TYPE xStatus;
	uint16_t temp=0;
	OWI *t_owi=pvParameters;

    while(1)
    {
	    DS18B20_Read_Struct(t_owi, &cur_temper );

//    	xStatus = xQueueSendToBack( xTemperQueue, &cur_temper, 0 );
//    	if( xStatus != pdPASS )  { }

    	vTaskDelay(500);
    }
    vTaskDelete(NULL);
}


/******************************************************************************/
uint8_t load_off_chan(uint8_t chan, uint8_t priority)
{
	if (out_get_state(&config.chan[chan] ) && config.load[chan].priority == priority)
	{
		auto_ch_off(&config.chan[chan] );
		config.load[chan].off_status = 1;
		return 1;
	}
	return 0;
}

/******************************************************************************/
uint8_t load_on_chan(uint8_t chan, uint8_t priority)
{
	if (out_get_state(&config.chan[chan] ) && config.load[chan].priority == priority)
	{
		auto_ch_on(&config.chan[chan] );
		config.load[chan].off_status = 1;
		return 1;
	}
	return 0;
}


/******************************************************************************/
void vLoadControllTask(void *pvParameters)
{
	TickType_t xLastWakeTime;
	const TickType_t xFrequency = 200;		// 200 ms
	uint16_t timeout;
	uint8_t pwr_value, cur_priority = 0;
	uint8_t i, on_load, off_load;

#define DATA_TIMEOUT		15*(1000/200)	// 10s

	xLastWakeTime = xTaskGetTickCount();

	for (;;)
	{
		vTaskDelayUntil(&xLastWakeTime, xFrequency );

		if (config.load_cntrl_en)
		{
			if (xQueueReceive(xLoadQueue, (void * ) &pwr_value, 0 ))
			{
				timeout = 0;
		/**************** owerload ******************/
				if (pwr_value > 95)
				{
					i = 0;
					off_load = 0;
					do
					{
						off_load = load_off_chan(i, LOAD_PRIOR_LOW);
						i++;
					} while ((off_load == 0) && (i < NUM_OUTPUTS));


					if (off_load == 0)
					{
						i = 0;
						do
						{
							off_load = load_off_chan(i, LOAD_PRIOR_MEDIUM);
							i++;
						} while ((off_load == 0) && (i < NUM_OUTPUTS));
					}
		/**************** no owerload******************/
				} else
				{
					i = 0;
					on_load = 0;
					do
					{
						if ((config.load[i].off_status) && ((pwr_value + config.load[i].conn_pwr) < 95))
						{
							auto_ch_on(&config.chan[i] );
							config.load[i].off_status = 0;
							on_load = 1;
						}
						i++;
					} while ((on_load == 0) && (i < NUM_OUTPUTS));
				}

		/**************** no power data received ******************/
			} else
			{
				timeout++;
				if (timeout >= DATA_TIMEOUT)
				{
					timeout = DATA_TIMEOUT;
					uint16_t summ_ch_pwr = 0;
					for (i = 0; i < NUM_OUTPUTS; i++)
						if (out_get_state(&config.chan[i] )) summ_ch_pwr += config.load[i].conn_pwr;

					if (summ_ch_pwr > 95)
					{
						i = 0;
						while ((summ_ch_pwr > 95) && (i < NUM_OUTPUTS))
						{
							if (load_off_chan(i, LOAD_PRIOR_LOW)) summ_ch_pwr -= config.load[i].conn_pwr;
							i++;
						}
					}
					if (summ_ch_pwr > 95)
					{
						i = 0;
						while ((summ_ch_pwr > 95) && (i < NUM_OUTPUTS))
						{
							if (load_off_chan(i, LOAD_PRIOR_MEDIUM)) summ_ch_pwr -= config.load[i].conn_pwr;
							i++;
						}
					}

				}

			}

		} else xQueueReceive(xLoadQueue, (void * ) &pwr_value, 0 );

	}
	vTaskDelete(NULL );
}


 /******************************************************************************/
static void system_clock_setup(void)
{
	// Enable external high-speed oscillator 4MHz.
	rcc_osc_on(RCC_HSE );
	rcc_wait_for_osc_ready(RCC_HSE );

	rcc_set_hpre(RCC_CFGR_HPRE_SYSCLK_NODIV );
	rcc_set_ppre1(RCC_CFGR_PPRE1_HCLK_NODIV );
	rcc_set_ppre2(RCC_CFGR_PPRE2_HCLK_NODIV );

	rcc_peripheral_enable_clock(&RCC_APB1ENR, RCC_APB1ENR_PWREN );
	pwr_set_vos_scale(PWR_SCALE1 );

	// Configure flash settings.
	flash_64bit_enable();
	flash_prefetch_enable();
	flash_set_ws(FLASH_ACR_LATENCY_1WS );

	// 4MHz * 12/2  = 24MHz
	rcc_set_pll_configuration(RCC_CFGR_PLLSRC_HSE_CLK, RCC_CFGR_PLLMUL_MUL12, RCC_CFGR_PLLDIV_DIV2 );
	rcc_osc_on(RCC_PLL );
	rcc_wait_for_osc_ready(RCC_PLL );
	rcc_set_sysclk_source(RCC_CFGR_SW_SYSCLKSEL_PLLCLK );

	rcc_apb1_frequency = 24000000;
	rcc_apb2_frequency = 24000000;
	rcc_ahb_frequency = 24000000;
}

/******************************************************************************/
void usart1_setup(void)
{
	usart_1.usart = USART1;
	usart_1.baudrate = 57600;
	usart_1.rx_buf_ptr = (uint8_t *) usart1_rx_buf;
	usart_1.tx_buf_ptr = (uint8_t *) usart1_tx_buf;
	usart_1.rx_buf_size = USART1_RX_BUF_SIZE;
	usart_1.tx_buf_size = USART1_TX_BUF_SIZE;

	// Setup GPIO pins for usart1 transmit.
	gpio_mode_setup(PORT(USART1_TX_PIN ), GPIO_MODE_AF, GPIO_PUPD_NONE, PIN(USART1_TX_PIN ) );
	// Setup usart1 TX pin as alternate function.
	gpio_set_af(PORT(USART1_TX_PIN ), GPIO_AF7, PIN(USART1_TX_PIN ) );
	// Setup GPIO pins for usart1 receive.
	gpio_mode_setup(PORT(USART1_RX_PIN ), GPIO_MODE_AF, GPIO_PUPD_NONE, PIN(USART1_RX_PIN ) );
	// Setup usart1 RX pin as alternate function.
	gpio_set_af(PORT(USART1_RX_PIN ), GPIO_AF7, PIN(USART1_RX_PIN ) );

	rcc_periph_clock_enable(RCC_USART1 );
	uart_init(&usart_1 );
	// Enable the usart1 interrupt.
	nvic_enable_irq(NVIC_USART1_IRQ );
}

/******************************************************************************
void usart2_setup(void)
{
	usart_2.usart = USART2;
	usart_2.baudrate = 9600;
	usart_2.rx_buf_ptr = (uint8_t *) usart2_rx_buf;
	usart_2.tx_buf_ptr = (uint8_t *) usart2_tx_buf;
	usart_2.rx_buf_size = USART2_RX_BUF_SIZE;
	usart_2.tx_buf_size = USART2_TX_BUF_SIZE;

	// Setup GPIO pins for USART2 transmit.
	gpio_mode_setup(PORT(USART2_TX_PIN ), GPIO_MODE_AF, GPIO_PUPD_NONE, PIN(USART2_TX_PIN ) );
	// Setup USART2 TX pin as alternate function.
	gpio_set_af(PORT(USART2_TX_PIN ), GPIO_AF7, PIN(USART2_TX_PIN ) );
	// Setup GPIO pins for USART2 receive.
	gpio_mode_setup(PORT(USART2_RX_PIN ), GPIO_MODE_AF, GPIO_PUPD_NONE, PIN(USART2_RX_PIN ) );
	// Setup USART2 RX pin as alternate function.
	gpio_set_af(PORT(USART2_RX_PIN ), GPIO_AF7, PIN(USART2_RX_PIN ) );

	rcc_periph_clock_enable(RCC_USART2 );
	uart_init(&usart_2 );
	// Enable the USART2 interrupt.
	nvic_enable_irq(NVIC_USART2_IRQ );
}


/******************************************************************************/
void save_config(void)
{
	eeprom_program_words(CONF_ADDR, (uint32_t *)&config, sizeof(config)/4 );
}

/******************************************************************************/
void load_config(void)
{
	uint32_t* ptr;

	ptr=(uint32_t *)&config;

	for (int i=0; i< sizeof(config)/4; i++)
	{
		*ptr = MMIO32(CONF_ADDR + (i*4) );
		ptr = ptr + 1;
	}
}

/******************************************************************************/
uint8_t config_modified(void)
{
	uint32_t* ptr;

	ptr=(uint32_t *)&config;

	for (int i=0; i< sizeof(config)/4; i++)
	{
		if ( *ptr != MMIO32(CONF_ADDR + (i*4) ) )	return 1;
		ptr = ptr + 1;
	}
	return 0;
}


/******************************************************************************/
void init_owi(void)
{
	const OWI_STM32F0xx_Pin sens_pin = {EXT_PIN_1};

	t_sensor_pindriver.interface=OWI_STM32F0XX_PINDRIVER_INTERFACE;
	t_sensor_pindriver.pin=sens_pin;
	t_sensor.gpios=(OWI_GPIO_Interface*)&t_sensor_pindriver;
	t_sensor.delay_microseconds=delay_us;
	t_sensor.owi_device_n=1;
}

/******************************************************************************
void init_power_on_exti(void)
{
	gpio_mode_setup(PORT(PWR_ON_PIN), GPIO_MODE_INPUT, GPIO_PUPD_NONE, PIN(PWR_ON_PIN));
	exti_select_source(PIN(PWR_ON_PIN), PORT(PWR_ON_PIN));
	exti_set_trigger(PIN(PWR_ON_PIN), EXTI_TRIGGER_BOTH);
	exti_enable_request(PIN(PWR_ON_PIN));
	exti_reset_request(PIN(PWR_ON_PIN));
	nvic_clear_pending_irq(NVIC_EXTI15_10_IRQ);
	nvic_enable_irq(NVIC_EXTI15_10_IRQ);
}


/******************************************************************************/
//----------------------------
// initializations
//----------------------------
void vFreeRTOSInitAll()
{
	system_clock_setup();

	rcc_periph_clock_enable(RCC_GPIOA );
	rcc_periph_clock_enable(RCC_GPIOB );
	rcc_periph_clock_enable(RCC_GPIOC );
	rcc_periph_clock_enable(RCC_GPIOD );
	rcc_periph_clock_enable(RCC_GPIOF );


//	gpio_mode_setup(PORT(LED_GREEN ), GPIO_MODE_OUTPUT, GPIO_PUPD_NONE, PIN(LED_GREEN ) );
//	init_power_on_exti();

	delay_init();
	init_owi();
	DS18B20_Init(&t_sensor, DS18B20_12BIT_RES);

	rtc_hl_init();

	usart1_setup();
//	usart2_setup();
	slip_1_protocol_init();

//	all_config_init();	save_config();
	load_config();

	lcd_set_br_cntr(config.lcd_brightness, config.lcd_contrast);

	out_channels_init(&config);
	out_ch_pwm_init();

	network_init();

	for (uint8_t i = 0; i < 6; i++)
		xButtons_Smphr[i] = xSemaphoreCreateCounting(10, 0 );
	xLoadQueue=xQueueCreate( 4, sizeof( uint8_t ));
}

void vApplicationIdleHook(void)
{

}

void vApplicationTickHook(void)
{
	static uint16_t dhcp_tm_cnt=0, save_conf_cnt = 0;

	MilliTimer_Handler();

	if (dhcp_tm_cnt >= DHCP_TMOUT_CNT)
	{
		DHCP_time_handler(); // DHCP Timer Handler for timeout counter ( 1 sec )
		dhcp_tm_cnt = 0;
	}
	dhcp_tm_cnt++;

	if (save_conf_cnt >= CONFIG_SAVE_FREQ)
	{
		if (config_modified() ) save_config();			// save config to eeprom if modified
		save_conf_cnt = 0;
	}
	save_conf_cnt++;

}

/******************************************************************************/
int main(void)
{
	vFreeRTOSInitAll();

//	xTemperQueue=xQueueCreate( 5, sizeof( DS18B20_TypeDef ));
	xTaskCreate(vGetTempTask,(signed char*)"", configMINIMAL_STACK_SIZE * 4 ,&t_sensor, tskIDLE_PRIORITY + 1, NULL);
	xTaskCreate(vLcdOutTask, (signed char*) "", configMINIMAL_STACK_SIZE * 4, NULL, tskIDLE_PRIORITY + 1, NULL );
	xTaskCreate(vReceiveButtonStateTask, (signed char*) "", configMINIMAL_STACK_SIZE * 4, NULL, tskIDLE_PRIORITY + 1, NULL );
	xTaskCreate(vEthernet_Task,(signed char*)"", configMINIMAL_STACK_SIZE * 4,	NULL, tskIDLE_PRIORITY + 1, NULL);
	xTaskCreate(vChanTimerTask,(signed char*)"", configMINIMAL_STACK_SIZE * 2,	NULL, tskIDLE_PRIORITY + 1, NULL);
	xTaskCreate(vPWMTimerTask,(signed char*)"", configMINIMAL_STACK_SIZE * 4,	NULL, tskIDLE_PRIORITY + 1, NULL);

	xTaskCreate(vLoadControllTask,(signed char*)"", configMINIMAL_STACK_SIZE * 2,	NULL, tskIDLE_PRIORITY + 1, NULL);

	vTaskStartScheduler();

	for (;;)	{	}
}

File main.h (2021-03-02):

/*
 * main.h
 *
 *  Created on: 21 ���. 2014 �.
 *      Author: kulish_y
 */

#ifndef MAIN_H_
#define MAIN_H_

#include <stdint.h>
#include <stdlib.h>
#include <stdio.h>
#include <string.h>

#include <libopencm3/cm3/assert.h>
#include <libopencm3/stm32/rcc.h>
#include <libopencm3/cm3/nvic.h>
#include <libopencm3/stm32/exti.h>
#include <libopencm3/stm32/flash.h>
#include <libopencm3/stm32/gpio.h>
#include <libopencm3/stm32/usart.h>
#include <libopencm3/stm32/pwr.h>
#include <libopencm3/stm32/spi.h>


#include "FreeRTOS.h"
#include "task.h"
#include "queue.h"
#include "semphr.h"

#include <slip_prot.h>
#include <slip_prot_uart_drv.h>
#include "my_libs/convert_fn.h"
#include "my_libs/delay.h"
#include "my_libs/pwm.h"
#include "my_libs/usart_hl.h"
#include <rtc_hal.h>


#include "socket.h"	// Just include one header for WIZCHIP
#include "DHCP/dhcp.h"
#include "SNTP/sntp.h"
#include "MQTT/MQTTClient.h"

#include "my_libs/w5500_spi.h"


#include <lcd_menu.h>
#include <out_ch.h>
#include <mqtt.h>

#include "owi/owi.h"
#include "owi/owi_stm32f0xx.h"
#include "owi/ds18b20.h"

//#define CRITICAL_SECTION_START	taskENTER_CRITICAL();
//#define CRITICAL_SECTION_END	taskEXIT_CRITICAL();

//#define last_page  FLASH_BASE + (127 * 1024)

// EEPROM ADRESSES
#define BASE_ADDR 0x08080000
#define CONF_ADDR BASE_ADDR


#define DATA_BUF_SIZE   2048   // TCP

#define USART1_RX_BUF_SIZE	128
#define USART1_TX_BUF_SIZE	128

#define USART2_RX_BUF_SIZE	64
#define USART2_TX_BUF_SIZE	64

/**** PINs defines *******/
#define LED_GREEN				GPIOA, GPIO5

#define LCD_MCU_RESET_PIN		GPIOA, GPIO8
#define USART1_TX_PIN			GPIOA, GPIO9
#define USART1_RX_PIN			GPIOA, GPIO10

#define USART2_TX_PIN			GPIOA, GPIO2
#define USART2_RX_PIN			GPIOA, GPIO3

//#define PWR_ON_PIN			GPIOC, GPIO13

#define CH_AC_1				GPIOB, GPIO13
#define CH_AC_2				GPIOB, GPIO14
#define CH_DC_5V_1				GPIOB, GPIO8
#define CH_DC_5V_2				GPIOB, GPIO9
#define CH_DC_12V_1			GPIOB, GPIO7
#define CH_DC_12V_2			GPIOB, GPIO6

#define EXT_PIN_1				GPIOA, GPIO7			// temp sensor
//#define EXT_PIN_2				GPIOB, GPIO0			// not connected !!! 3.3v only
#define EXT_PIN_3				GPIOB, GPIO1
#define EXT_PIN_4				GPIOB, GPIO10
#define EXT_PIN_5				GPIOB, GPIO11
/**** end PINs defines *******/

#define	ETHER_TASK_FRQ 		(100)
#define SNTP_RUN_FRQ			 (30*60*(1000/ETHER_TASK_FRQ))		// 30 min
#define SNTP_ERR_FRQ			 (1*(1000/ETHER_TASK_FRQ))		// 1 s
#define DHCP_RUN_FRQ		 	(5*60*(1000/ETHER_TASK_FRQ))		// 5 min
#define MQTT_CH_DAT_FRQ		(3*(1000/ETHER_TASK_FRQ))		// 3 s
#define MQTT_TM_DAT_FRQ		(10*(1000/ETHER_TASK_FRQ))		// 10 s

#define DHCP_TMOUT_CNT		(1*(1000))							// 1 s
#define CONFIG_SAVE_FREQ		(30*(1000))						// 30 s

#define 	MQTT_SERV_PORT 1883

#define 	SOCK_DHCP		7
#define 	SOCK_NTP		6
#define 	SOCK_MQTT		5



#define DEVICE_ADDR		0x01
#define CLOCK_INIT		12,30


void save_config(void);
void load_config(void);
uint8_t config_modified(void);


// modes
#define temper_out		0
#define temper_set		1


#endif /* MAIN_H_ */

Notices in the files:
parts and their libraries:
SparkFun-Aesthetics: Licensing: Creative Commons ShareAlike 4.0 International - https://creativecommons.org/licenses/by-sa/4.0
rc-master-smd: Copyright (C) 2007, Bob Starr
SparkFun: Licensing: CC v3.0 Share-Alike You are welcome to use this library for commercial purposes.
